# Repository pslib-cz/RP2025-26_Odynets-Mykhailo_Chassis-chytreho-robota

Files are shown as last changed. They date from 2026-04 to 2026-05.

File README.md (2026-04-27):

# Chassis robota Bessie

Сhassis 3D tištěného vozítka, které se může stát základem platformy chytrého robota Bessie

## Progress

[Figma](https://www.figma.com/board/z2sys4jyA4PsdDyRYrDXgL/Ideas?node-id=0-1&t=Aov2YQ2UH2wKDupg-1)

[Ročníková práce](https://prace.pslib.cz/works/6831)

## Code

MakeCode knihovna pro ovládání krokových motoru  
[https://github.com/Mykhailo-Odynets/pxt-bessie](https://github.com/Mykhailo-Odynets/pxt-bessie)

Kód pro ovládání Bessie pro Micro:Bit  
[https://github.com/Mykhailo-Odynets/bessie-car_bit](https://github.com/Mykhailo-Odynets/bessie-car_bit)

## 📂 Struktura repozitáře
    /cad - Zdrojové soubory (např. STEP, f3d nebo odkaz na Onshape).
    /docs - manuály na replikaci a vysvětlení
    /electronics - Součástky, schémata zapojení a fotky z montáže.

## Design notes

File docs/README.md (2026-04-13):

# Documentation

docs is for text (manuals, explanations). How to build and run the robot

## Files to add:

- raspberry_conf - how to configure raspberry pi for this robot
- setup_guide
- photos of the finished robot

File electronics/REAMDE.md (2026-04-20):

# Electronics

electronics/ is for data (wiring diagrams, component datasheets, pinout maps).

## 🛠 Seznam komponent

Micro:bit sestava:

| Kategorie | Komponenta | Specifikace |
|---|---|---|
| 🚗 Pohon | 2x DC Motor | Krokový 28BYJ-48 |
| ⚖️ Stabilizace | 1x Caster Wheel | Otočné kuličkové kolečko (v ložisku) |
| 🧠 Řízení | Micro:bit | Hlavní procesorová jednotka |
| ⚡ Výkonová část | Micro:bit PCB | Robot:Bit |
| 📡 Senzorika (Dálka)| Ultrasonický senzor | HC-SR04 pro detekci překážek |
| 🛣 Senzorika (Trasa)| IR Senzor | TCRT5000 pro sledování čáry |
| 🔩 Spojovací materiál | Šrouby a matice | Nerezové M3 (různé délky) |

Raspberry Pi sestava:

| Kategorie | Komponenta | Specifikace |
|---|---|---|
| 🚗 Pohon | 2x DC Motor | Krokový 28BYJ-48 |
| ⚖️ Stabilizace | 1x Caster Wheel | Otočné kuličkové kolečko (v ložisku) |
| 🧠 Řízení | Raspberry Pi | Hlavní procesorová jednotka |
| ⚡ Výkonová část | Motor Driver | ULN2003 |
| 📡 Senzorika (Dálka)| Ultrasonický senzor | HC-SR04 pro detekci překážek |
| 🛣 Senzorika (Trasa)| IR Senzor | TCRT5000 pro sledování čáry |
| 👁️ Senzorika (Obraz) | Kamera | Např. Raspberry Pi Camera Module |
| 🧭 Senzorika (Mapování) | LiDAR | Např. VL53L0X / RPLIDAR |
| 🖥️ Výstup | Displej | Malý (např. SSD1306, I2C) |
| 🔋 Napájení | Akumulátor | Li-ion pack (7.4V) nebo powerbanka |
| 🔩 Spojovací materiál | Šrouby a matice | Nerezové M3 (různé délky) |

## Things to add:

- parts list
- wiring_diagram
- circuit_schematic

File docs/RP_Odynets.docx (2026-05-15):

Střední průmyslová škola a Vyšší odborná škola, Liberec, příspěvková organizace

Chassis chytrého robota

Ročníková práce

Autor Mykhailo Odynets

Obor Informační technologie

Vedoucí práce Ing. Tomáš Kazda

Školní rok 2025/2026

Počet stran 3

Počet slov 1032

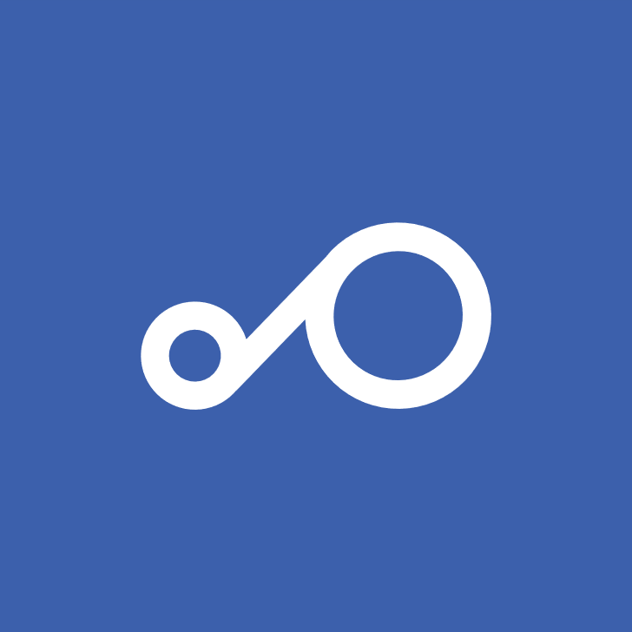
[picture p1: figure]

# Anotace

Práce se zabývá …

Vychází z …

Přináší …

# Summary

This work …

# Čestné prohlášení

Prohlašuji, že jsem tuto práci vypracoval/a samostatně. V práci jsem použil/a pouze zdroje uvedené v seznamu literatury a všechny převzaté části, včetně textů, obrázků, kódu a výstupů umělé inteligence, jsou řádně označeny a citovány.

V Liberci dne 15.05.2026

Mykhailo Odynets

# Úvod

Práce se zabývá vytvořením autonomního autíčka pro sledování čáry, které bude využíváno pro závěrečný programovací projekt prvních ročníku oboru IT. Zahrnuje definování požadavku společně s vedoucím prací (panem Kazdou), výběr komponent, vytvoření 3D modelu podvozku na míru, vytištění na 3D tiskárně, zapojení a dokumentace procesu sestavení kompletního autíčka s fotodokumentaci. Taky byla vytvořená MakeCode knihovna pro přesné ovládání krokových motoru z pohledu autíčka.

# 1 Teorie

Před začátkem práce na 3D modelu autíčka je nutný mít teoretický základ v elektronice, robotice a trošku i strojařině. Bez žádných zkušenosti to byl můj první milník v tomto projektu, který jsem měl nastudovat a ovládnout.

## 1.1 Základy robotiky a elektroniky

Každá součástka budoucího robota potřebuje specifické elektrické požadavky ke správnému fungování, definované v datasheetu. Bez jich dodržení hrozí spálení, zničení nebo nepředpovídané chovaní komponent. To může vest k fatálním chybám při provozovaní autíčka.

Základem elektřiny je Ohmův zákon, který má jednoduchý vzorec definovaný takto:

U = I × R

U je napětí ve Voltech = tlak, pod kterým elektrický náboj protéká obvodem.

I je proud = množství elektrického náboje protékajícího obvodem.

R je odpor = vlastnost materiálu bránit průtoku proudu.

V elektronice máme základní napětí 3,3V, 5V a 12V. Mikrokontroler robota (v mém případě Micro:bit) pracuje s nízkým napětím (typicky 3,3 V) a velmi malými proudy. Když motory pro svojí práci potřebuji minimálně 5V a mnohem větší spotřebu v mA.

Při přímém propojení těchto součástek by došlo ke spálení té slabší (mikrokontroleru). Aby tomu předejít, musím použít motor drivery, které řídí vysoko napěťový zdroj pomocí málo napěťového signálu.

## 1.2 Průzkum existujících řešení

Před začátkem prací jsem zkoumal internet pro již existující řešení 3D modelu autonomních autíček, které se shodují s mými požadavky. Podle toho jsem taky vybíral komponenty.

Původní plán byl modulární design, kde podvozek se skládá s univerzálních plátku s předem definovanými otvory pro přišroubování držáku. Tato konstrukce zajišťuje velkou modularitu, rychlý prototypování a flexibilitu designu, což znamená snadnou výměnu součástek, pro které stačí jen vyrobit vhodný držák a základna zůstane stejná. To by dost pomohlo pro následný upgrady nebo úplné přestavení autíčka pro osobní účely.

Nevýhodou takového systému, na kterou jsem narazil, je nedostatek optimalizace a přizpůsobeni na míru. Solidní, předdefinovaný podvozek má specializovaná místa pro každou součástku, což pomáhá optimalizovat využiti místa, definovat cesty pro kabely, jejich délku. Je to doladěný systém pro specifické použití, který ale v dlouhodobé perspektivě bude lepší volbou.

Po uvážení všech za a proti, moje volba padla na solidní podvozek navržený pro specifické komponenty.

## 1.3 Výběr komponent

Jelikož autíčko bude používáno především pro školní účely, při výběru komponent jsem se primárně radil s vedoucím práce, abychom jsme si vzájemně porozuměli a výsledný produkt byl funkční přesně podle požadavku a účelu použití.

Základem celého systému se stal britský mikrokontroler Micro:Bit, který má jednoduchou architekturu a byl vyvinut primárně pro výukové účely. Ale sám o sobě nestačí pro zapojení motoru a senzoru. Je potřeba rozhraní pinu, motor drivery, měnič napětí a vlastně zdroj elektřiny (baterka). To vše můžeme najít na specializované pro robotické projekty desce RobotBit, kterou i budu používat.

Hlavním požadavkem na motory byla možnost přesného ovládaní. Pro tento účel se nejlíp budou hodit krokové motory. Vybral jsem model 28BYJ-48. Jsou levné, dají se sehnat všude a jejich výkon absolutně stačí pro takhle jednoduchý a malý projekt.

Účelem robota je autonomní řízení, které je dosaženo sledováním okolí. K tomu slouží různé senzory. Pro sledování čáry jsem vybral infračervený senzor TCRT5000, který je v dostatečné zásobě u nás na škole a spolehlivě splňuje svůj účel. Pro měření vzdálenosti k překážce jsem vybral ultrazvukový senzor HC-SR04, ze stejných důvodu.

# 2 Proces výroby

## 2.1 Požadavky na design

Design a konstrukce podvozku by měly být navržené s ohledem na snadnou reprodukovatelnost, vlastnosti 3D tisku a vedení kabelů. Taky důležitý aspektem je splnění účelu projektu, aby obsahoval všechny potřebné elektrické součástky a mechanické detaily.

Podle požadavku pana vedoucího, autíčko by mělo mít dva funkční kola pro pohyb a jedno opěrný kolečko pro zajištění rovnováhy podvozku. Tenhle systém zjednoduší logiku ovládaní motoru. Oproti klasickým čtyřkolým řešením, auto se tak dá otočit na místě bez použiti speciálně k tomu určených kol a složitých logických stavu.

Pro autonomní sledování čáry by pak měla být možnost její přesné identifikace. To znamená zjištění polohy autíčka: jestli je na čáře, jestli sjel z čáry, jestli musí mírně zabočit, jestli najel do křižovatky a tak dál. K tomu slouží infračervené senzory. Teoreticky by stačili jenom dva, pak by ale jízda nebyla plynula a autíčko poskakovalo ze strany na stranu. To by kladlo větší tlak na programátora, který by měl řešit tento problém softwarově a složitě. Proto bylo rozhodnuto použit tři infračervené senzory. Ten jeden navíc zajisti sledování stavu „na čáře“.

Autíčko by mělo mít možnost identifikace překážek. Proto je nutný použit ultrazvukový senzor. Ten je ale potřeba jenom jeden, protože auto dokáže jet jenom jedním směrem v určitou dobu. Takže vždy uvidí překážku. Pro případ couvaní stačí otočit se o 180 stupňů.

## 2.2 Fusion 360

Existuje spousta CAD programu, ve kterých jde použit techniku parametrického modelování. To je technika 3D navrhování, kde jsou tvary definovány parametry, kótami a geometrickými vazbami. Vzhledem k použití ve škole Fusion 360, mám k tomu licenci a taky dostačující znalosti k vytvoření podvozku. Proto výběr softwaru nebyl problémem.

## 2.3 Rozměry

Před začátkem modelování jsem musel pozorně změřit a zaznamenat přesné rozměry elektronických součástek. Šířku, výšku, hloubku, tvar a případné rozměry specifické pro danou komponentu. Například očí u ultrazvukového senzorů. Bez toho by nešlo vytvořit správný model.

První měření jsem prováděl pomocí obyčejného kancelářského pravítka, což nebylo dostatečně přesný ani pohodlný používat. Následně jsem začal používat kovové posuvné měřítko a výsledný model se mnohem zlepšil.

## 2.4 Modelování

Základem šasi je nosná deska obdélníkového průřezu, která slouží jako základna pro integraci všech subsystémů. V konstrukci jsou precizně rozmístěny montážní otvory pro upevnění rozšiřující desky RobotBit a stabilizačního otočného kolečka.

### 2.4.1 Stabilizace

Stabilizační kolečko je situováno v zadní části šasi v ose pod deskou RobotBit. Tato pozice byla zvolena s ohledem na optimální distribuci hmotnosti; RobotBit představuje nejtěžší prvek sestavy, a proto se v této oblasti nachází výsledné těžiště platformy. Kolečko tak zajišťuje statickou stabilitu a zamezuje převracení robotu při akceleraci. Druhý bod zatížení tvoří přední náprava s pohonnými jednotkami a senzorickou výbavou.

### 2.4.2 Pohonný systém

Uchycení motorů je řešeno pomocí bočních držáků v přední části šasi. Konstrukční řešení umožňuje fixaci motorů prostým zasunutím (s využitím třecí síly), avšak pro zvýšení mechanické odolnosti a eliminaci vibrací jsou držáky opatřeny výřezy pro šroubové spoje. Výška hřídele motoru nad podložkou je navržena v korelaci s průměrem kol a výškou stabilizačního kolečka tak, aby byla rovina šasi paralelní s povrchem. Použitá kola jsou předem připravená a plně kompatibilní s hřídelemi zvolených motorů.

### 2.4.3 Senzorický systém

#### 2.4.3.1 Infračervené senzory

Trojice senzorů je orientována kolmo k podložce pro detekci vodicí čáry. Dva senzory jsou umístěny po stranách v přední části, zatímco třetí je situován v ose otáčení mezi motory. Tato konfigurace umožňuje přesné trasování čáry a predikci směru pohybu. V šasi jsou integrovány výřezy pro těla senzorů, výřezy pro kabeláž a díry pro mechanické upevnění šrouby.

#### 2.4.3.2 Ultrazvukový senzor

Senzor pro detekci překážek je umístěn na čelní hraně robotu. Jeho pozice je zarovnána tak, aby vysílač a přijímač lícovaly s obrysem šasi. Senzor je fixován ve speciálním držáku (vkládaná destička), který obsahuje přesné výřezy pro měniče, kondenzátor a kabeláž. Tento modul se následně zasouvá do drážek mezi držáky motorů. Konektory senzoru jsou orientovány směrem vzhůru pro snadné připojení.

### 2.4.4 Řídicí elektronika a management kabeláže

Řídicí deska RobotBit je umístěna v zadní části nad stabilizačním kolečkem. Je instalována na vyvýšených podpěrách (distancích), které pod deskou vytvářejí prostor pro uspořádání kabeláže. Fixace desky k šasi je realizována pomocí prvků kompatibilních se systémem LEGO, což usnadňuje montáž i demontáž. Vodiče od senzorů a motorů jsou vedeny v prostoru pod deskou a vyvedeny po stranách přímo k pinům RobotBitu, což minimalizuje riziko mechanického poškození nebo rozpojení konektorů během provozu.

## 2.5 Prototypování a iterace

### 2.5.1 Analýza prvního prototypu

Realizace prvního prototypu ukázala značný rozdíl mezi teoretickým 3D modelem a fyzickým výtiskem. Tento proces potvrdil, že aditivní výroba je specifická technologie vyžadující precizní zohlednění tolerancí a mechanických vlastností materiálu. Prvotní sestavení odhalilo zásadní chyby v rozměrech, kdy uložení motorů i držák ultrazvukového senzoru vykazovaly příliš těsné lícování, které znemožňovalo montáž komponentů. Ergonomie zapojení byla rovněž nevyhovující; ultrazvukový senzor byl orientován konektory směrem dolů a celková koncepce kabeláže nebyla dostatečně promyšlena, což vedlo k nepřehlednému uspořádání vodičů.

Další kritické body se týkaly geometrie a polohování senzorů. Otvory pro infračervené (IR) senzory neodpovídaly skutečným rozměrům součástek a upevňovací body pro šrouby byly mimo osu. Nevhodné bylo také lineární uspořádání středového IR senzoru s ostatními prvky, což negativně ovlivňovalo jeho funkčnost. Podvozek jako celek byl neúměrně velký, vykazoval nežádoucí sklon směrem dopředu a fixační otvory pro rozšiřující desku RobotBit byly umístěny chybně. Tento stav vyžadoval kompletní revizi modelu a přechod k procesu iterativního vylepšování.

### 2.5.2 Optimalizace a úpravy

Na základě zkušeností získaných z první tiskové zkoušky byla zahájena fáze postupné optimalizace 3D modelu. Celý vývoj zahrnoval celkem pět generací prototypu, během nichž byly postupně odstraňovány identifikované vady. Mezi nejvýznamnější úpravy patřila rekonfigurace umístění IR senzorů a zvětšení prostoru pro jejich konektory, což usnadnilo celkovou manipulaci a zapojení. Orientace ultrazvukového senzoru byla změněna otočením konektorů směrem vzhůru, čímž se zefektivnilo vedení kabeláže k řídicí jednotce.

Strukturální změny se dotkly také stability a rozložení hmotnosti celého robotu. Pozice motorů byla posunuta níže, čímž se eliminoval předchozí náklon podvozku a zlepšilo se těžiště stroje. Pro spolehlivé ukotvení elektroniky byly do modelu integrovány dedikované sloupky odpovídající rozteči desky RobotBit. V rámci finálního ladění rozměrů byly odstraněny nadbytečné technologické otvory a celkové rozměry šasi byly redukovány na nezbytné minimum. Výsledkem těchto úprav je kompaktní a plně funkční konstrukce, která odpovídá původním technickým požadavkům.

# 3 Programování

Jedním z požadavku daného projektu byl kód pro přesný pohyb autíčka. Jelikož pro pohon byly použité krokové motory, které mají 4 drátky k ovládání a nutnost dodržet specifickou sekvenci posílání signálu, softwarová část projektu bude o něco složitější než při programování DC motoru, které mají jenom dva drátky a funguji na principu zapnout/vypnout.

Pro programování vybraného mikrokontroleru(mikrobitu) se používá webová aplikace MakeCode, kde programování probíhá v blocích, Javascriptu, Typescriptu a Pythonu. Vzhledem k předchozím zkušenostem a pohodlí použiti byl vybrán Typescript.

## 3.1 Základ projektu

Po konzultaci s vedoucím práce byla zjištěná již existující knihovna v MakeCodu pro ovládaní motoru. Ta se ale zaměřuje hlavně na DC motory a servomotory, ale taky obsahuje základní ovládání krokových motoru, i když některé funkce jsou implementovány ne nejlepším a nejvhodnějším způsobem pro reální využiti.

Hlavní nevýhodou knihovny je ovládání motoru z pohledu motoru, nikoli z pohledu autíčka. To vyvolalo potřebu vytvoření nové knihovny, která bude navazovat a rozšiřovat již existující řešení pro specifické účely ovládaní autíčka.

## 3.2 Vývoj vlastní knihovny

Knihovna by měla zajistit ovládaní auta z pohledu auta samotného. Měly by být implementované funkce pro otočení vozítka o daný stupeň a projíždějí určité vzdálenosti v centimetrech. Taky by neměla chybět možnost pro ovládání motoru přímo, pro kompletní a robustní systém. Výsledný kód bude pořádně a srozumitelně zdokumentován, včetně podpory programovaní v blocích.

Vlastní knihovna byla založená na GitHubu přes prostředí MakeCodu. Open-source projekt zle najít na odkazu https://github.com/Mykhailo-Odynets/pxt-bessie.git. Obsahuje dvě složky: pohyb a kalibrace hodnot. Tady budou popsané jenom nejdůležitější funkce.

### 3.2.1 Funkce pro pohyb

#### 3.2.1.1 CarRotate()

export function CarRotate(degree: number, spinInPlace = true) : void {

const degreeToRotate = spinInPlace ? degree * Calibration.getCarDiameter() / Calibration.getWheelDiameter() : degree;

const m1Direction = spinInPlace ? -1 : 1;

// Starts the first motor in the background

control.inBackground(() => {

MotorRotate(Motors.M1, degreeToRotate * m1Direction);

});

MotorRotate(Motors.M2, degreeToRotate);

MotorStop(Motors.Both);

}

Ukázka znázorňuje kód funkce pro otočení autíčkem o určitý stupeň. Základem vnitřní logiky je funkce MotorRotate(), která otočí jednotlivý motor směrem dopředu auta o určitý stupeň. Proto je potřeba předat opačné hodnoty do dvou motoru, aby se točily různými směry a auto se točilo na místě.

Stupeň, o který se musejí otočit jednotlivá kola je odvozen od poměru průměru kola a průměru auta, což je vzdálenost mezi středy dvou kol. Výsledný vzorec pak vypadá takto:

Stupeň k otočení motoru = Stupeň k otočení auta * průměr auta / průměru kola

#### 3.2.1.2 CarMove()

export function CarMove(distance: number, diameter?: number) : void {

const circumference = Math.PI * (diameter ? diameter : Calibration.getWheelDiameter());

const degreeToRotate = (distance * 10 / circumference) * 360;

CarRotate(degreeToRotate, false);

}

Tato funkce pomocí vzorce počítá o kolik stupňů se musejí otočit kola, aby autíčko projelo určitou vzdálenost v centimetrech. Následně tato hodnota je předaná do funkce CarRotate() s volitelným parametrem nastaveným na false. To zajisti, aby auto jelo dopředu místo točení na místě.

### 3.2.2 Funkce pro kalibraci

Pro správné výpočty je potřeba nastavit průměry kola a autíčka. Nastavené hodnoty se uloží napevno do pamětí MicroBitu a jsou dostupné i po přeflashování mikrokontroleru. Výchozí nastavení jsou již přizpůsobená rozměrům autíčka.

Manuálně v kódu to jde udělat pomocí funkci setWheelDiameter(), setWheelDiameterFromMeasuredDistance() a setCarDiameter(), setCarDiameterFromWheelRotations().

Pro pohodlí a volbu jsou připravené funkce pro kalibraci hodnot v reálním čase. startWheelCalibration(), stopWheelCalibration() fungují na principu rozjezdu a zastavení na jednom metru. startCarCalibration(), stopCarCalibration() funguji na principu otočení podvozku o 360 stupňů. Tyto funkce se dají integrovat se vzdáleným ovladačem, a tak nastavit hodnoty za běhu programu, bez přímého měření rozměru.

# 4 Návod k replikaci

3D model autíčka byl navrhnout pro tisk na 3D tiskárně, bez nutnosti použiti podpor. Jsou to dva díly k tisku, tělo podvozku a držák pro ultrasonický senzor, které do sebe zapadají

## 4.1 Seznam součástek (BOM - Bill of Materials)

Přesný seznam elektroniky, šroubků a vytištěných dílů.

Pro

## 4.2 Instrukce k 3D tisku

Doporučený materiál (PLA/PETG), výplň (infill), případně nutnost podpor (supports).

## 4.3 Postup montáže

Krok za krokem podpořený tvými fotkami.

## 4.4 Zapojení elektroniky

Jak přesně zapojit kabely (wiring), jaké jsou naměřené a doporučené délky kabelů.

## 4.5 Oživení

Jak nahrát tvou MakeCode knihovnu a spustit první testovací kód.

# Závěr

Zhodnocení výsledků

Podařilo se splnit všechny cíle z Úvodu? Je autíčko mechanicky odladěné a funkční?

Možnosti dalšího rozvoje

Zde zmiň tu „navazující práci“ – co všechno se na tuto platformu chytrého robota dá v budoucnu přidat (např. složitější AI, kamera, ruka...).

# Seznam zkratek a odborných výrazů

IR

Infračervený senzor – infračervený přijímač nebo senzor, který detekuje a zpracovává infračervené záření

# Seznam obrázků

# Použité zdroje

1. Němcová, Božena. Babička. Praha : Odeon, 2021. ISBN 978-80-207-2063-4.

# A. Seznam přiložených souborů

Na přiloženém datovém nosiči se nacházejí následující soubory a složky:

- MP2010-Novák-Jan-L4-Tepelné_čerpadlo.docx – editovatelná verze dokumentace maturitní práce
- MP2010-Novák-Jan-L4-Tepelné_čerpadlo.pdf – tisknutelná verze dokumentace maturitní práce
- Výkresy – kompletní výkresová dokumentace
- Aplikace – zdrojové kódy

Chassis chytrého robota

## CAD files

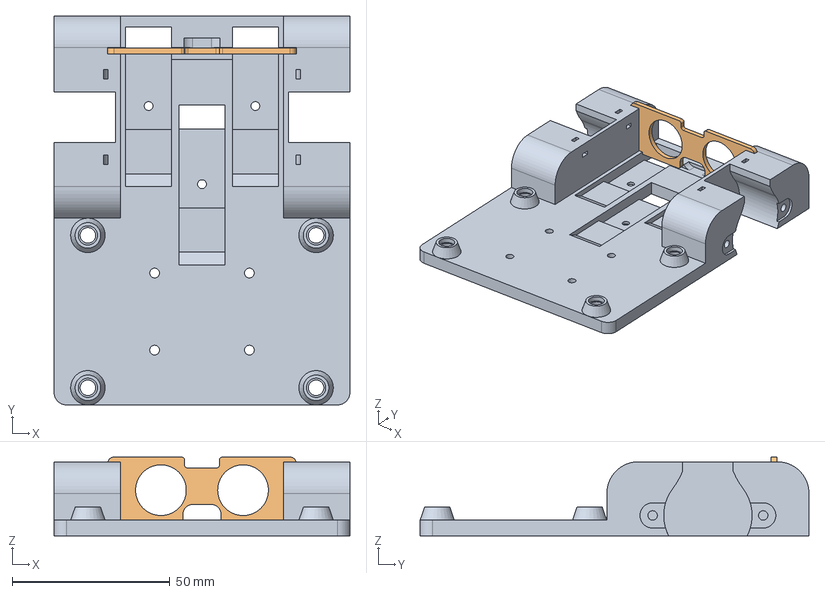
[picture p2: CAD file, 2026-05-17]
cad/Master.step
93.7 x 123.2 x 25.0 mm
Plate
UltrasonicHolder

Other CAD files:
cad/Master.3mf
cad/Master.f3d
cad/Master.stl

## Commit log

2026-03-28 Expand README with project prerequisites and components
    Added initial project requirements and components for the chassis.
2026-03-29 Update README with Figma link and pin table idea
    Added a link to Figma design and a note about creating a pin table.
2026-03-30 Change motor driver to ULN2003 and add inspiration
    Updated motor driver specification in the README and added a new inspiration section.
2026-04-21 3d files
    [Master.3mf, Master.f3d]
2026-04-27 Add Code section for MakeCode library
    Added a section for the MakeCode library for stepper motor control.
2026-04-29 model V2
    [Master.3mf, Master.f3d, Master.step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]
2026-05-15 DONE 2
    [Master.3mf, Master.f3d, Master.step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]
2026-05-17 3d model done
    [Master.3mf, Master.f3d, Master.step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]
